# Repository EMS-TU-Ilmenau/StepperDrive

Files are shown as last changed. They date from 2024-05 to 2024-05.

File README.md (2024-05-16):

# StepperDrive
This embedded project features a simple controller board for a stepper motor. 
Multiple boards can be connected together. 
One of it has to be attached to USB and power supply. 
Each motor can then be controlled with simple SCPI-like commands via UART (8N1 9600baud) to move to a position, set the maximum rate and acceleration etc.

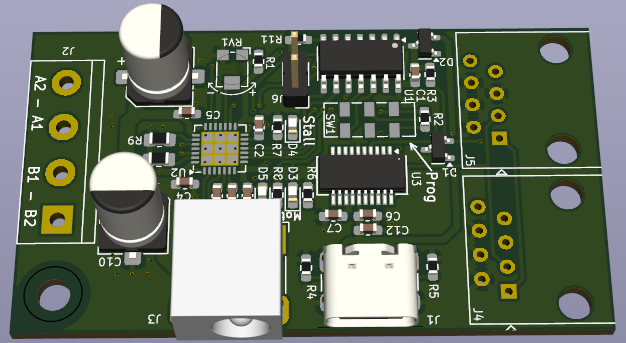
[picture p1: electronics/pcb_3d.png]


## Features
- Uses TMC2209 stepper driver IC for smooth and quiet operation
- Multiple boards can be connected to each other via ethernet-cables
- USB-C interface for control and flashing firmware

Note that there is no real anti-collision protocol, but as the communication is quit fast, there should be no problem to query each motors parameters individually with their IDs after another.
E.g. `AX1:POS?` then `AX2:POS?`.
Sending commands can be even done simultaneously, e.g. `AX1:POS 180;AX2:POS 22.5`.

## Flashing
The firmware is written in AVR-C for the ATtiny814. To start programming, an extended AVR toolchain is needed, which can be found in the Arduino IDE (the GNU AVR toolchain does NOT support the ATtiny814):
- Go to https://www.arduino.cc/en/software and scroll down to "legacy IDE (1.8.X)" and download the zipped version for your OS
- Unzip and add 
  - (Linux) *arduino-1.8.19-linux64.tar/arduino-1.8.19-linux64/arduino-1.8.19/hardware/tools/avr/bin* or 
  - (Windows) *arduino-1.8.19-windows\arduino-1.8.19\hardware\tools\avr\bin* 
  
  to your systems PATH variable (the rest of the IDE is not needed)
- Install [Make](https://www.gnu.org/software/make/#download) if you have it not already

To transfer the firmware to the microcontroller, install [pymcuprog](https://pypi.org/project/pymcuprog/).
Switch to **Prog** on the PCB.
Edit the PROGRAMMER variable (serial port) in the [firmware/Makefile](Makefile) and run `make flash clean` to build, flash and remove the built files.

## Commands
#### Common rules
Commands are simple ascii strings (no binary shenanigans, so human readable), terminated with `\n` (linefeed).
The string length must not exceed 64 chars in total (could be raised probably, not tested).
The commands have to be send with 9600 baud, 8 byte, no parity and 1 stop bit (8N1).

At the moment, only one command is parsed for each axis at a time, i.e. it is not possible to set the rate and position for a motor in one string.
However, it is possible to send one command to each motor simultaneously, by separating the commands with semicolons.
You can send commands and receive replies while the motor is moving, e.g. you can set a new position - the motor will instantly move to that position even it has not reached its last target position.

All commands must begin with `AX`, followed by the axis identifier number (default `1`) as specified with `AX1:ID <1...9>` (saved in EEPROM). 
If you forgot the ID, you can query it (works only when one controller board is connected to the hub) using `*IDN?`.

All parameters and subparameters have to be separated with a colon (`:`), followed by either a query (`?`) or the value.
E.g. `AX1:POS?`, `AX4:POW ON`, `AX2:LIM:MAX 360` or `AX3:SUB2`.
Note that the questionmark must follow immediately, while a value can have a leading white space (not required though).
When setting a parameter, it is possible to add `;*OPC?` afterwards to get feedback (`1` is returned) when the operation completed.

Commands are case-sensitive (all capital letters).

#### List of commands
- `:POW` [`ON` or `OFF`] Motor power on or off. Probably the first thing you do is to turn the power on. Default `OFF`.
- `:ACC` [positive integer] Acceleration factor. This controls how smooth the movement to a target position starts. A value of `1` is very smooth, while `100` is like constante rate. Default is `100`.
- `:DEC` [positive integer] Decceleration factor. This controls how smooth the movement to a target position ends. A value of `1` is very smooth, while `100` is like constante rate. Default is `10`.
- `:HOME` [float or integer] Moves the motor with given velocity in degree/s until the home sense pin goes low. After that, the position is defined as 0 degree. When requested, the reply is either `1` (at home) or `0` not homed/homing in progress.
- `:POS` [float or integer] Axis position (angle) in degree.
- `:LIM:MAX` [positive float or integer] Upper speed limit in degree/s. Must not be set higher than `8000*360/(substeps*steps_per_revolution)` (steps per revolution is set the in makefile and is 200 for most motors). Default 360.
- `:LIM:MIN` [positive float or integer] Lower speed limit in degree/s. Must not be set to 0. Default 10.
- `:RATE` [positive float or integer] Shorthand for `:LIM:MAX`.
- `:VEL` [positive float or integer] Rotates the axis infinitely with value in degree/s.
- `:SUB` [`8`, `16`, `32` or `64`] Number of substeps. Higher values will result in finer resolution and smoother movements, but also lower maximum rate. Default is `8`. **Important:** Set the substeps before setting or getting any parameter with degree related unit.

## TODOs
Currently, the TMC2209 is controlled via classic STEP, DIR, ENABLE, MS pins by the firmware. The hardware supports to configure the driver via its UART interface, for example to enable stall detection.

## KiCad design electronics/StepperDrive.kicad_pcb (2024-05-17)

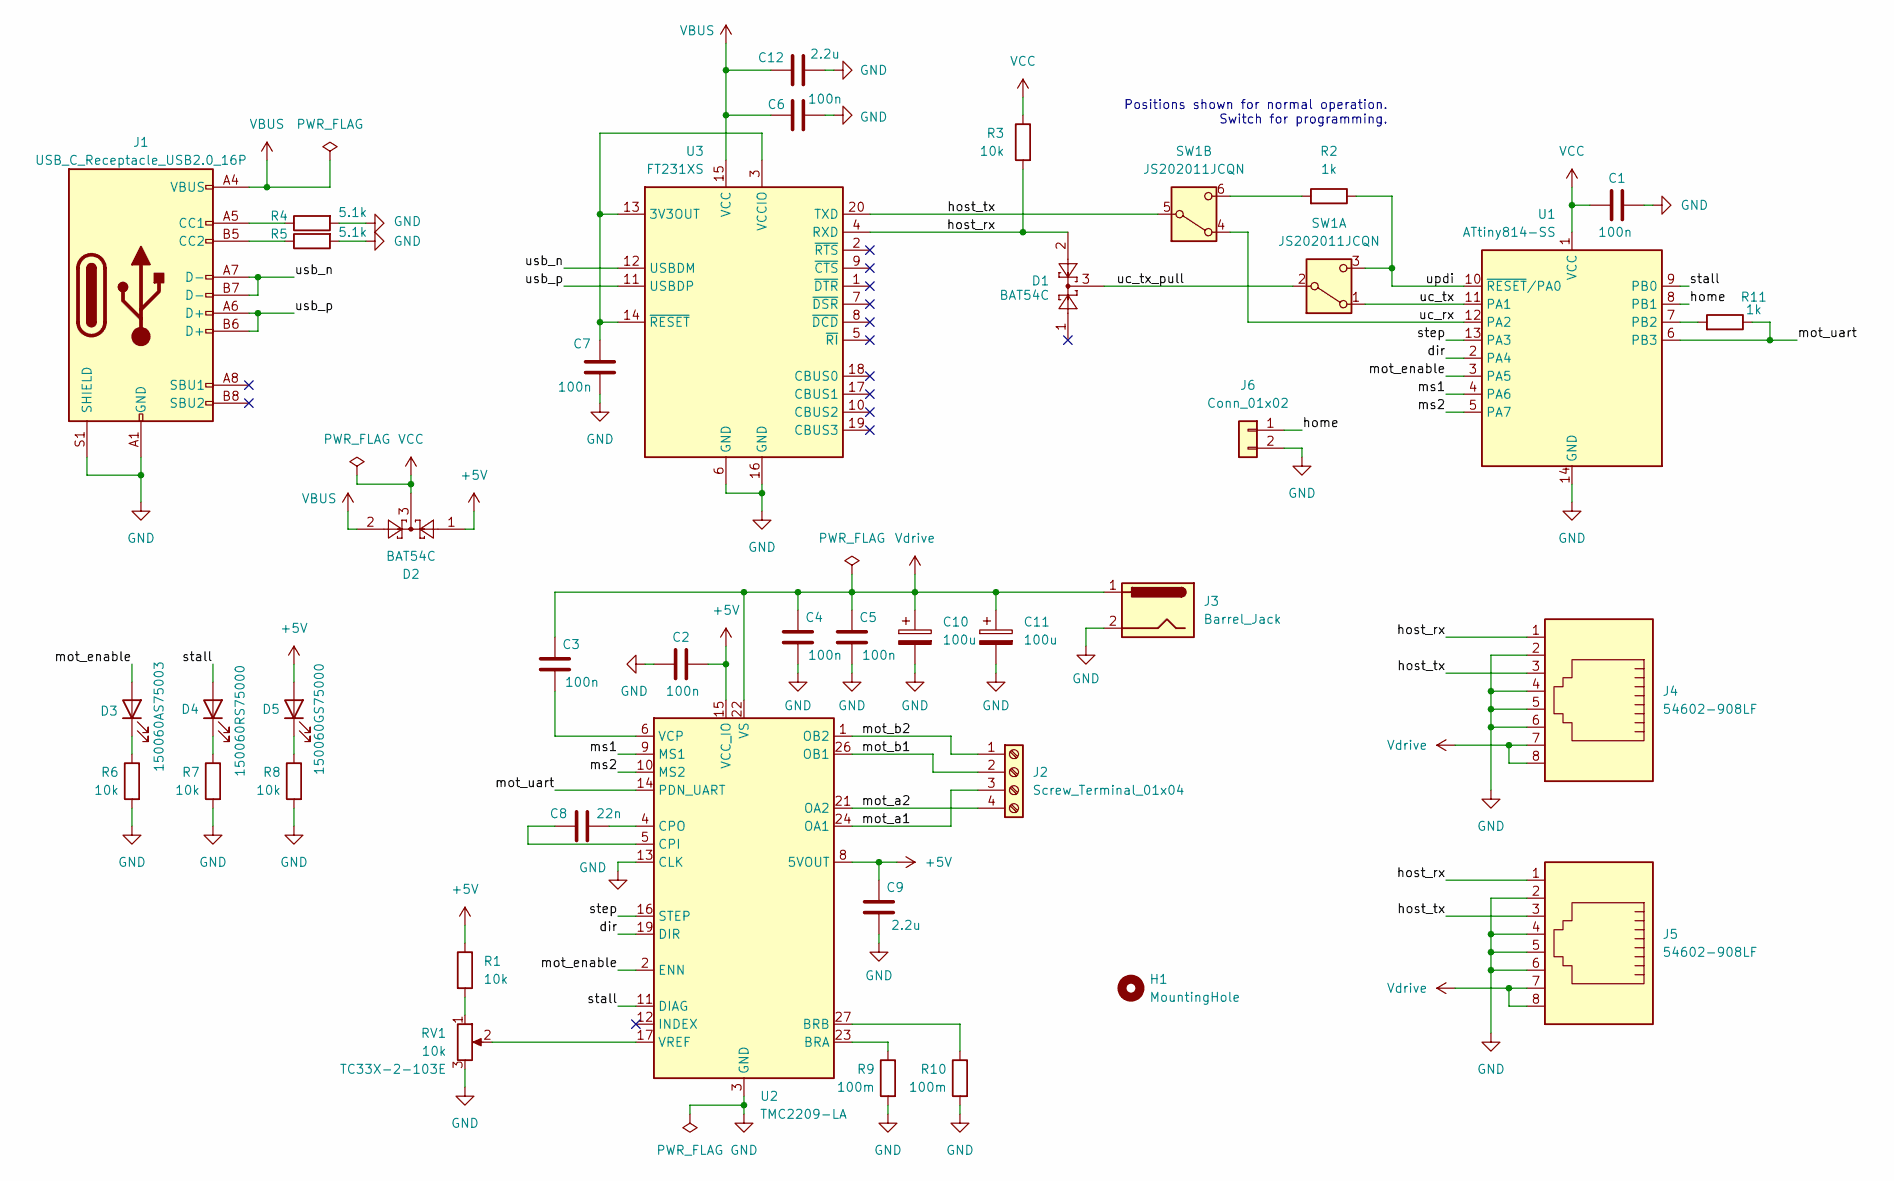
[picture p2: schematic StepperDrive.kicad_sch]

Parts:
C1, C2, C3, C4, C5, C6, C7: 100n; C_0603_1608Metric_Pad1.08x0.95mm_HandSolder
C8: 22n; C_0603_1608Metric_Pad1.08x0.95mm_HandSolder
C9, C12: 2.2u; C_0603_1608Metric_Pad1.08x0.95mm_HandSolder
C10, C11: 100u; CP_Elec_6.3x9.9
D1, D2: BAT54C; SOT-23
D3: 150060AS75003; LED_0603_1608Metric_Pad1.05x0.95mm_HandSolder
D4: 150060RS75000; LED_0603_1608Metric_Pad1.05x0.95mm_HandSolder
D5: 150060GS75000; LED_0603_1608Metric_Pad1.05x0.95mm_HandSolder
H1: MountingHole; MountingHole_3.2mm_M3_DIN965
J1: USB_C_Receptacle_USB2.0_16P; USB_C_Receptacle_GCT_USB4105-xx-A_16P_TopMnt_Horizontal
J2: Screw_Terminal_01x04; TerminalBlock_bornier-4_P5.08mm
J3: Barrel_Jack; BarrelJack_CUI_PJ-079BH_Horizontal
J4, J5: 54602-908LF; RJ45_Amphenol_54602-x08_Horizontal
J6: Conn_01x02; PinHeader_1x02_P2.54mm_Vertical
R1, R3, R6, R7, R8: 10k; R_0603_1608Metric_Pad0.98x0.95mm_HandSolder
R2, R11: 1k; R_0603_1608Metric_Pad0.98x0.95mm_HandSolder
R4, R5: 5.1k; R_0603_1608Metric_Pad0.98x0.95mm_HandSolder
R9, R10: 100m; R_0805_2012Metric_Pad1.20x1.40mm_HandSolder
RV1: 10k; Potentiometer_Bourns_TC33X_Vertical; MPN TC33X-2-103E
SW1: JS202011JCQN; SW_DPDT_CK_JS202011JCQN
U1: ATtiny814-SS; SOIC-14_3.9x8.7mm_P1.27mm
U2: TMC2209-LA; QFN-28-1EP_5x5mm_P0.5mm_EP3.75x3.75mm
U3: FT231XS; SSOP-20_3.9x8.7mm_P0.635mm

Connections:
+5V: C2.2, C9.2, D2.1, D5.2 (A), R1.1, U2.8 (5VOUT), U2.15 (VCC_IO)
/dir: U1.2 (PA4), U2.19 (DIR)
/home: J6.1, U1.8 (PB1)
/host_rx: D1.2, J4.1, J5.1, R3.2, U3.4 (RXD)
/host_tx: J4.3, J5.3, SW1.5 (B), U3.20 (TXD)
/mot_a1: J2.3, U2.24 (OA1)
/mot_a2: J2.4, U2.21 (OA2)
/mot_b1: J2.2, U2.26 (OB1)
/mot_b2: J2.1, U2.1 (OB2)
/mot_enable: D3.2 (A), U1.3 (PA5), U2.2 (ENN)
/mot_uart: R11.1, U1.6 (PB3), U2.14 (PDN_UART)
/ms1: U1.4 (PA6), U2.9 (MS1)
/ms2: U1.5 (PA7), U2.10 (MS2)
/stall: D4.2 (A), U1.9 (PB0), U2.11 (DIAG)
/step: U1.13 (PA3), U2.16 (STEP)
/uc_rx: SW1.4 (A), U1.12 (PA2)
/uc_tx: SW1.1 (A), U1.11 (PA1)
/uc_tx_pull: D1.3, SW1.2 (B)
/updi: R2.1, SW1.3 (C), U1.10 (~RESET/PA0)
/usb_n: J1.A7 (D-), J1.B7 (D-), U3.12 (USBDM)
/usb_p: J1.A6 (D+), J1.B6 (D+), U3.11 (USBDP)
GND: C1.1, C2.1, C4.1, C5.1, C6.1, C7.1, C9.1, C10.2, C11.2, C12.1, J1.A1 (GND), J1.A12 (GND), J1.B1 (GND), J1.B12 (GND), J1.S1 (SHIELD), J3.2, J4.2, J4.4, J4.5, J4.6, J5.2, J5.4, J5.5, J5.6, J6.2, R4.2, R5.2, R6.2, R7.2, R8.2, R9.2, R10.2, RV1.3, U1.14 (GND), U2.3 (GND), U2.13 (CLK), U2.18 (GND), U2.29 (EP), U3.6 (GND), U3.16 (GND)
unnamed: D3.1 (K), R6.1
unnamed: D4.1 (K), R7.1
unnamed: D5.1 (K), R8.1
unnamed: J1.A5 (CC1), R4.1
unnamed: J1.B5 (CC2), R5.1
unnamed: R1.2, RV1.1
unnamed: R2.2, SW1.6 (C)
unnamed: R11.2, U1.7 (PB2)
unnamed: R9.1, U2.23 (BRA)
unnamed: R10.1, U2.27 (BRB)
unnamed: C8.2, U2.5 (CPI)
unnamed: C8.1, U2.4 (CPO)
unnamed: C3.1, U2.6 (VCP)
unnamed: RV1.2, U2.17 (VREF)
unnamed: C7.2, U3.3 (VCCIO), U3.13 (3V3OUT), U3.14 (~RESET)
VBUS: C6.2, C12.2, D2.2, J1.A4 (VBUS), J1.A9 (VBUS), J1.B4 (VBUS), J1.B9 (VBUS), U3.15 (VCC)
VCC: C1.2, D2.3, R3.1, U1.1 (VCC)
Vdrive: C3.2, C4.2, C5.2, C10.1, C11.1, J3.1, J4.7, J4.8, J5.7, J5.8, U2.22 (VS), U2.28 (VS)

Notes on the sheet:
Positions shown for normal operation. Switch for programming.

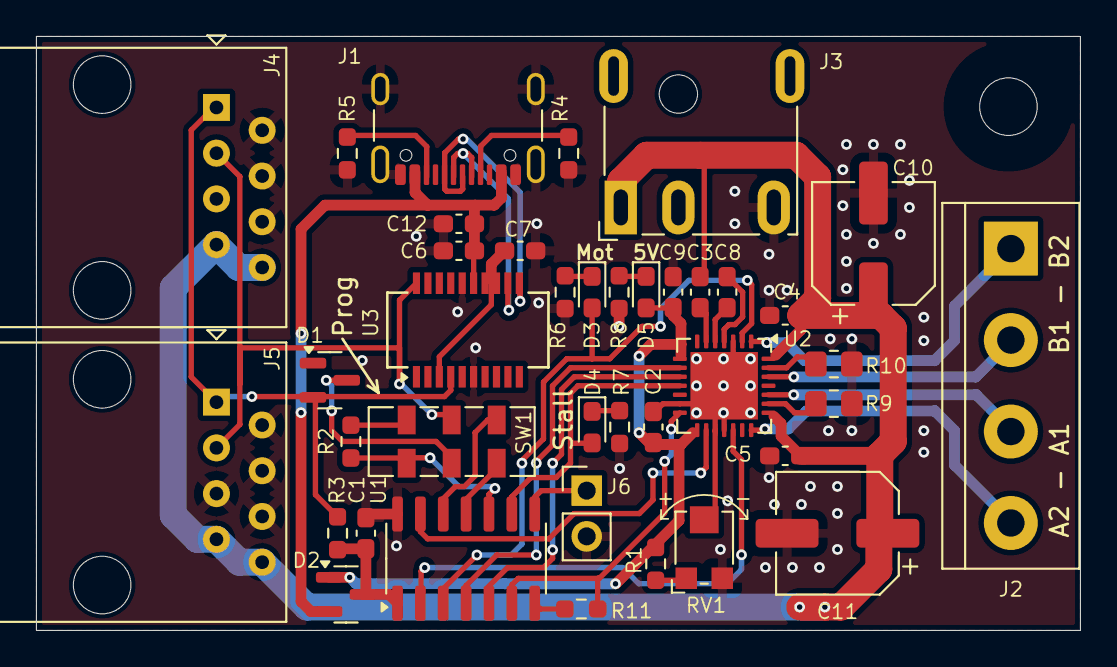
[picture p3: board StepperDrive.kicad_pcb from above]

Board: 2 copper layers, 58.0 x 33.0 mm, 40 parts (0 on the bottom side), 40 nets.

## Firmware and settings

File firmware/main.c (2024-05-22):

#include <avr/io.h> // for microcontroller specific peripheral definitions
#include <stdint.h> // for uint8_t, uint16_t, etc.
#include <string.h>	// for string operations like cmp and cat
#include <stdlib.h>	// for itoa, atoi
#include <avr/interrupt.h>	// for sei(), cli() and ISR():
#include <util/delay.h> // for waiting
#include "main.h" // for application specific definitions

ISR(USART0_RXC_vect) {
	char nextChar = USART0.RXDATAL; // new char available

	// track received string
	static uint8_t charCnt = 0;
	if (nextChar != STR_TERM && charCnt < UART_MAXSTRLEN) {
		// still getting valid chars
		uartRecvStr[charCnt++] = nextChar;
	} else {
		// end of string
		uartRecvStr[charCnt] = '\0';
		charCnt = 0;
		gotCommand = TRUE;
	}
}

int main() {
	// setup
	configClock();

	// init
	maxStepRate = degToSteps(360);
	minStepRate = degToSteps(10);
	
	// read axis ID
	_delay_ms(100); // let voltage stabilize, otherwise eeprom read is corrupted
	uint8_t storedID = eeprom_read_byte(&eAxisIDAddr);
	if ((storedID < 48) || (storedID > 57)) {
		// initially store ID from default command string
		storedID = cmdID[2];
		eeprom_write_byte(&eAxisIDAddr, storedID);
	}
	cmdID[2] = storedID;

	// continue setup
	configGPIO();
	configUART();
	configTCA();
	sei();
	
	// main program loop
	while (TRUE) {
		// parse incoming
		if (gotCommand) {
			parseCommand((char*)uartRecvStr);
			gotCommand = FALSE;
		}

		// timer interrupt flag
		if (TCA0.SINGLE.INTFLAGS & TCA_SINGLE_OVF_bm) {
			TCA0.SINGLE.INTFLAGS |= TCA_SINGLE_OVF_bm; // clear flag
			if (moving == pos) {
				// position control loop
				static uint16_t tic = 0;
				if (tic++ >= C_PRESC) {
					// perform control step
					tic = 0;
					controlStep();
				}
			}
			if (ctrlState.tic++ >= ctrlState.stepPeriod) {
				// perform physical step
				ctrlState.tic = 0;
				phyStep();
			}
		}

		// check for home
		if ((homing == search) && (!(PORTB.IN & PIN_HOME))) {
			// switch activated, stop motor
			ctrlState.curStepPos = 0;
			ctrlState.tarStepPos = 0;
			ctrlState.oldStepPos = 0;
			moving = pos;
			homing = found;
		}
	}
	return 0;
}

void parseCommand(const char* strP) {
	// parse command (SCPI style, but not protocol conform)
	// search entry point: our axis with ID ("AX<ID>")
	char* cmdP = strstr(strP, cmdID);
	if (cmdP) {
		cmdP += 4; // skip "AX<ID>:"
		if (strncmp(cmdP, "ID", 2) == 0) {
			// change axis ID
			cmdP += 3; // skip "ID "
			uint8_t id = *cmdP;
			if ((id >= 48) && (id <= 57)) {
				cmdID[2] = id;
				for (uint8_t nTries = 3; nTries > 0; nTries--) {
					eeprom_update_byte(&eAxisIDAddr, id);
					uint8_t storedID = eeprom_read_byte(&eAxisIDAddr);
					if (storedID == id) break;
				}
			}
		} else if (strncmp(cmdP, "POW", 3) == 0) {
			// enable/disable power
			cmdP += 3;
			if (*cmdP == '?') {
				// host wants to know if the motor power is enabled (low active)
				sendUARTString((PORTA.OUT & PIN_ENABLE) ? "OFF" : "ON");
			} else {
				// host wants to set the motor power
				/*
				note: loosing power results in unknown state of the position, so reset it
				Same goes when powering on because there is no absolute encoder
				*/
				ctrlState.curStepPos = 0;
				ctrlState.tarStepPos = 0;
				ctrlState.oldStepPos = 0;
				cmdP += 2; // skip " O"
				if (*cmdP == 'N') {
					PORTA.OUTCLR = PIN_ENABLE;
				} else {
					PORTA.OUTSET = PIN_ENABLE;
				}
			}
		} else if (strncmp(cmdP, "ACC", 3) == 0) {
			// acceleration proportion
			cmdP += 3;
			if (*cmdP == '?') {
				sendNum(kAcc);
			} else {
				kAcc = (uint16_t)(strtoul(cmdP, NULL, RADIX));
			}
		} else if (strncmp(cmdP, "DEC", 3) == 0) {
			// decceleration proportion
			cmdP += 3;
			if (*cmdP == '?') {
				sendNum(kDec);
			} else {
				kDec = (uint16_t)(strtoul(cmdP, NULL, RADIX));
			}
		} else if (strncmp(cmdP, "HOME", 4) == 0) {
			// start homing
			cmdP += 4;
			if (*cmdP == '?') {
				// requested for home status (1 = on home and motor stopped, 0 not)
				sendNum((homing == found) ? 1 : 0);
			} else {
				// set homing velocity (with sign)
				stepVel = degStrToSteps(cmdP);
				move(stepVel);
				homing = search;
			}
		} else if (strncmp(cmdP, "VEL", 3) == 0) {
			// velocity (moving without target position)
			cmdP += 3;
			if (*cmdP == '?') {
				sendStepsAsDeg(stepVel);
			} else {
				stepVel = degStrToSteps(cmdP);
				move(stepVel);
				homing = off;
			}
		} else if (strncmp(cmdP, "POS", 3) == 0) {
			// target position
			cmdP += 3;
			if (*cmdP == '?') {
				sendStepsAsDeg(ctrlState.curStepPos);
			} else {
				ctrlState.tarStepPos = degStrToSteps(cmdP);
				homing = off;
				moving = pos;
			}
		} else if (strncmp(cmdP, "SUB", 3) == 0) {
			// substeps
			cmdP += 3;
			if (*cmdP == '?') {
				sendNum(substeps);
			} else {
				substeps = (uint8_t)(strtoul(cmdP, NULL, RADIX));
				setSubsteps(substeps);
			}
		} else if (strncmp(cmdP, "RATE", 4) == 0) {
			// rate (shorthand for LIM:MAX)
			cmdP += 4;
			if (*cmdP == '?') {
				sendStepsAsDeg(maxStepRate);
			} else {
				maxStepRate = degStrToSteps(cmdP);
			}
		} else if (strncmp(cmdP, "LIM", 3) == 0) {
			// rate limit
			cmdP += 4; // skip "LIM:"
			if (strncmp(cmdP, "MAX", 3) == 0) {
				// max rate
				cmdP += 3;
				if (*cmdP == '?') {
					sendStepsAsDeg(maxStepRate);
				} else {
					maxStepRate = degStrToSteps(cmdP);
				}
			}
			if (strncmp(cmdP, "MIN", 3) == 0) {
				// min rate
				cmdP += 3;
				if (*cmdP == '?') {
					sendStepsAsDeg(minStepRate);
				} else {
					minStepRate = degStrToSteps(cmdP);
				}
			}
		} else {
			// no valid command
			strcpy(uartSendStr, "No valid command: ");
			strcat(uartSendStr, cmdP);
			sendUARTString(uartSendStr);
		}
		// query operation complete
		cmdP = strstr(cmdP, "*OPC?");
		if (cmdP) {
			sendUARTString("1");
		}
	} else {
		// no axis specific command
		cmdP = strstr(strP, "*IDN?");
		if (cmdP) {
			// requested for device name
			sendUARTString(cmdID);
		}
	}
}

void configClock() {
	// configure CPU frequency to 10 MHz
	CCP = CCP_IOREG_gc; // disable protection to configure clock frequency
	CLKCTRL.MCLKCTRLA = CLKCTRL_CLKSEL_OSC20M_gc; // use 20 MHz internal clock as source
	CCP = CCP_IOREG_gc; // disable protection to configure clock frequency
	CLKCTRL.MCLKCTRLB = CLKCTRL_PDIV_2X_gc | CLKCTRL_PEN_bm; // prescale divider
}

void configGPIO() {
	// inputs
	PORTB.DIRCLR = PIN_STALL | PIN_HOME;
	PORTB.PIN1CTRL |= PORT_PULLUPEN_bm; // enable pullup for home

	// outputs
	PORTA.DIRSET = PIN_ENABLE | PIN_STEP | PIN_DIR | PIN_MS1 | PIN_MS2;
	PORTA.OUTSET = PIN_ENABLE; // disable motor power
	PORTA.OUTCLR = PIN_MS1 | PIN_MS2; // configure substeps to 1/8
}

void configUART() {
	USART0.BAUD = (uint16_t)UART_BAUD_RATE(9600); // set baudrate
	USART0.CTRLB |= USART_RXEN_bm | USART_TXEN_bm; // enable RX | TX
	USART0.CTRLA |= USART_RXCIF_bm; // enable interrupt on receive complete
	// use alternative UART pins
	PORTMUX_CTRLB |= PORTMUX_USART0_bm; // enable alternative UART pins
	PORTA.DIRCLR = PIN2_bm; // PA2 as input (RX)
	PORTA.DIRSET = PIN1_bm; // PA1 as output (TX)
}

void sendUARTChar(const char c) {
	while (!(USART0.STATUS & USART_DREIF_bm)); // wait until the transmit DATA register is empty
	USART0.TXDATAL = c; // put char into buffer
}

void sendUARTString(const char* strP) {
	// for all characters in string until '\0'
	while(*strP && (*strP != STR_TERM)) {
		sendUARTChar(*strP++);
	}
	// append string termination
	sendUARTChar(STR_TERM);
}

void configTCA() {
	// configures 16 bit timer counter A
	// set normal mode (default)
	TCA0.SINGLE.CTRLA = TCA_SINGLE_CLKSEL_DIV2_gc | TCA_SINGLE_ENABLE_bm; // count with prescale 2 and enable timer
	TCA0.SINGLE.PER = (F_CPU/2/F_TINT)-1; // set TOP (10000000 Hz CPU / 2 timer prescale / 8000 Interrupts/s) - 1 cycle = 624
}

void setSubsteps(uint8_t ss) {
	PORTA.OUTCLR = PIN_MS1 | PIN_MS2; // ss == 8
	// set substep pins
	if (ss == 16) {
		PORTA.OUTSET = PIN_MS1 | PIN_MS2;
	} else if (ss == 32) {
		PORTA.OUTSET = PIN_MS1;
	} else if (ss == 64) {
		PORTA.OUTSET = PIN_MS2;
	}
}

int32_t degToSteps(int32_t deg) {
	// same as steps = deg*substeps/stepangle
	return deg*substeps*FSTEP_REV/360;
}

int32_t stepsToDeg(int32_t steps) {
	// same as deg = steps*stepangle/substeps
	return steps*360/(substeps*FSTEP_REV);
}

int32_t degStrToSteps(const char* strP) {
	// parses the string for float degree and converts to steps
	char *nxt;
	int32_t num = strtol(strP, &nxt, RADIX);
	if (*nxt == '.') {
		// float detected
		// get 2 fractional digits
		uint8_t i;
		for (i = 0; i < 2; i++) {
			nxt++;
			char c = *nxt;
			if ((c >= 48) && (c <= 57)) {
				if (num > 0) {
					num = num*10 + c-48;
				} else {
					num = num*10 - (c-48);
				}
			} else {
				num = num*10;
			}
		}
		// convert to steps
		return degToSteps(num)/100;
	} else {
		return degToSteps(num);
	}
}

void sendStepsAsDeg(int32_t steps) {
	// converts steps to degree in float and sends it over USART
	int32_t num = stepsToDeg(steps*100); // for 2 fractional digits
	ldiv_t deg = ldiv(num, 100);
	// quotient
	itoa(deg.quot, uartSendStr, RADIX);
	strcat(uartSendStr, "."); // float point
	// fractional digits (remainder)
	char fracDigs[3];
	itoa(abs(deg.rem), fracDigs, RADIX);
	strcat(uartSendStr, fracDigs);
	// send
	sendUARTString(uartSendStr);
}

void sendNum(int16_t num) {
	// converts a decimal number to string and sends it over USART
	itoa(num, uartSendStr, RADIX);
	sendUARTString(uartSendStr);
}

void controlStep() {
	// control loop step
	int32_t tarVel = kDec*(ctrlState.tarStepPos - ctrlState.curStepPos);
	int32_t oldVel = kAcc*(ctrlState.curStepPos - ctrlState.oldStepPos);
	// sign
	uint32_t tarRate;
	uint32_t oldRate;
	if (tarVel > 0) {
		ctrlState.tarDir = 1;
		tarRate = tarVel;
		oldRate = oldVel;
	} else if (tarVel < 0) {
		ctrlState.tarDir = -1;
		tarRate = -tarVel;
		oldRate = -oldVel;
	} else {
		ctrlState.tarDir = 0;
		tarRate = 0;
		oldRate = 0;
	}
	// limit rate
	tarRate = (tarRate < oldRate) ? tarRate : oldRate; // choose acceleration or decceleration ramp
	if (tarRate > maxStepRate) tarRate = maxStepRate;
	if (tarRate < minStepRate) tarRate = minStepRate;
	// update step period
	ctrlState.stepPeriod = F_TINT/tarRate;
}

inline void phyStep() {
	// perform a step
	if (ctrlState.tarDir != 0) {
		// set direction
		if (ctrlState.tarDir > 0) {
			PORTA.OUTSET = PIN_DIR; // physical +
		} else {
			PORTA.OUTCLR = PIN_DIR; // physical -
		}
		// step
		PORTA.OUTSET = PIN_STEP;
		ctrlState.curStepPos += ctrlState.tarDir;
		PORTA.OUTCLR = PIN_STEP;
	}
}

void move(int32_t vel) {
	ctrlState.stepPeriod = F_TINT/abs(vel);
	if (vel == 0) {
		ctrlState.tarDir = 0;
		ctrlState.tarStepPos = ctrlState.curStepPos;
		ctrlState.oldStepPos = ctrlState.curStepPos;
	} else if (vel > 0) {
		ctrlState.tarDir = 1;
	} else if (vel < 0) {
		ctrlState.tarDir = -1;
	}
	moving = vel;
}

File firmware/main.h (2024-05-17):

#include <avr/io.h> // for microcontroller specific peripheral definitions
#include <stdint.h> // for uint8_t, uint16_t, etc.
#include <avr/eeprom.h> // for storing axis ID permanently

// defines
#define FSTEP_REV 200 // number of full steps of the motor
#define UART_BAUD_RATE(BAUD_RATE) ((float)(F_CPU*64/(16*(float)BAUD_RATE))+0.5)
#define STR_TERM '\n'
#define UART_MAXSTRLEN 64
#define RADIX 10 // for itoa
#define TRUE 1
#define FALSE 0
#define F_TINT 8000 // timer interrupt frequency
#define C_PRESC 64 // control frequency that much slower than F_TINT
#define PIN_STEP PIN3_bm
#define PIN_DIR PIN4_bm
#define PIN_ENABLE PIN5_bm // low active
#define PIN_MS1 PIN6_bm
#define PIN_MS2 PIN7_bm
#define PIN_STALL PIN0_bm
#define PIN_HOME PIN1_bm // low active, needs pullup configuration

// own types
struct control {
	int32_t tarStepPos;
	int32_t curStepPos;
	int32_t oldStepPos;
	uint16_t tic;
	uint16_t stepPeriod;
	int8_t tarDir;
} ctrlState;

enum home {
	off, 
	search, 
	found
};

enum mode {
	pos, 
	vel
};

// variables
volatile char uartRecvStr[UART_MAXSTRLEN] = "";
char uartSendStr[UART_MAXSTRLEN] = "";
char cmdID[] = "AX1"; // axis specific commands must start with AX<id>
uint8_t EEMEM eAxisIDAddr; // address pointer for axis ID stored in eeprom
uint8_t gotCommand = FALSE;
uint8_t substeps = 8; // num of microsteps which make 1 full step
uint16_t maxStepRate, minStepRate; // step rate limits
int32_t stepVel; // step velocity
uint16_t kAcc = 100; // acceleration proportion
uint16_t kDec= 10; // decceleration proportion
enum home homing = off; // homing state
enum mode moving = pos; // movement mode

// prototypes
void configClock();
void configGPIO();
void configUART();
void sendUARTChar(char c);
void sendUARTString(const char* strP);
void configTCA();
void parseCommand(const char* strP);
int32_t degToSteps(int32_t deg);
int32_t stepsToDeg(int32_t steps);
void sendNum(int16_t num);
void controlStep();
void phyStep();
void setSubsteps(uint8_t ss);
int32_t degStrToSteps(const char* strP);
void sendStepsAsDeg(int32_t steps);
void move(int32_t speed);

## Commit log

2017-10-18 Added notes why the ugly PCB
2017-10-18 Inverted PCB images to make it more printer friendly
2017-10-18 Try to make schematic and PCB images appear next to each other
2017-12-05 Fixed bug that caused to ignore the first received message from the host. Requesting the IDN now only returns the actual axis identifier.
    [main.c]
2017-12-05 The first message from the host is still ignored because of hardware reasons (serial port produces random bytes when plugged), so reverted the fix
    [main.c]
2019-09-02 Added rate parameter as shorthand for LIM:MAX for compatibility to old pcb
    [main.c]
2020-05-28 Fixed setting 16 substeps
    [main.c]
2020-05-29 added acceleration. Replaced KP by ACC and DEC factors
    [main.c, main.h]
2020-07-01 replaced sendNum by correct parsing functions for each parameter
    [main.c, main.h]
2020-07-01 to reduce interrupts, USART chars are now received in main loop. String termination is now only linefeed
2024-05-16 all new board with TMC2209 driver and without the need of an hub.
    [Hub.brd, Hub.sch, Stepper control circuit.brd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]
2024-05-17 fixed potential problem when reading or writing the axis ID
    [main.c]
2024-05-17 added GND Via for stall LED
    [StepperDrive.kicad_pcb]
2024-05-17 minor fixes for potential problems
    [main.c, main.h]
2024-05-22 removed repeated eeprom read as there seems no effect. Fixed float parsing
    [main.c]
